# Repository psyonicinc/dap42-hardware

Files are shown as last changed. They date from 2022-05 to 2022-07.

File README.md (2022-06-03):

# dap42-hardware

This is a design of the dap42 in KiCad v6 using the STM32F103C8, there is no technical reason for this design and this STM is overkill. The re-design only part availability reasons. This design is based on dap42 v2 and [dc37's dap42 v3 design](https://github.com/dc37/dap42-hardware). 

Please see the parent repo at [devanlai/dap42-hardware](https://github.com/devanlai/dap42-hardware) for details on the DAP42 project. 

This design primarily uses the [KiCad default libraries](https://gitlab.com/kicad/libraries) which are expected to be in the global library table. A few footprints not in the KiCad Libraries are included in dap42.pretty which is configured as a project specific library. 

Firmware for this version to follow.

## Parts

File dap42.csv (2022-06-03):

Source: | F:\Psyonic\repos\dap42-hardware\dap42.kicad_sch
Date: | 6/3/2022 4:39:25 PM
Tool: | Eeschema (6.0.5)
Generator: | C:\Program Files\KiCad\6.0\bin\scripting\plugins/bom_csv_grouped_by_value_with_fp.py
Component Count: | 32
Ref | Qnty | Value | Cmp name | Footprint | Description | Vendor
C1, | 1 | 1uF 0603 | C | Capacitor_SMD:C_0603_1608Metric_Pad1.08x0.95mm_HandSolder | Unpolarized capacitor
C2, | 1 | 4.7uF 0603 | C | Capacitor_SMD:C_0603_1608Metric_Pad1.08x0.95mm_HandSolder | Unpolarized capacitor
C3, | 1 | 100nF 0402 | C | Capacitor_SMD:C_0402_1005Metric_Pad0.74x0.62mm_HandSolder | Unpolarized capacitor
C4, C5, C6, C7, C8, C9, C10, | 7 | 0.1uF 0402 | C | Capacitor_SMD:C_0402_1005Metric_Pad0.74x0.62mm_HandSolder | Unpolarized capacitor
D1, | 1 | 5.6V | D_Zener | Diode_SMD:D_SOD-123F | Zener diode
D2, | 1 | Green 0603 | LED | LED_SMD:LED_0603_1608Metric_Pad1.05x0.95mm_HandSolder | Light emitting diode
D3, | 1 | LED_GBAR | LED_GBAR | dap42:B38G3RGB | RGB LED, green/blue/anode/red
F1, | 1 | PTC 250mA 1206 | Polyfuse | Fuse:Fuse_1206_3216Metric_Pad1.42x1.75mm_HandSolder | Resettable fuse, polymeric positive temperature coefficient
J1, | 1 | USB_B_Micro | USB_B_Micro | Connector_USB:USB_Micro-B_Molex_47346-0001 | USB Micro Type B connector
J2, | 1 | Conn_02x05_Odd_Even | Conn_02x05_Odd_Even | dap42:IDC-Header_2x05_Pitch1.27mm_Straight | Generic connector, double row, 02x05, odd/even pin numbering scheme (row 1 odd numbers, row 2 even numbers), script generated (kicad-library-utils/schlib/autogen/connector/)
J4, | 1 | Conn_01x04 | Conn_01x04 | Connector_PinHeader_2.54mm:PinHeader_1x04_P2.54mm_Vertical | Generic connector, single row, 01x04, script generated (kicad-library-utils/schlib/autogen/connector/)
R2, R4, R5, R6, R7, R8, R10, | 7 | 1k 0402 | R_US | Resistor_SMD:R_0402_1005Metric_Pad0.72x0.64mm_HandSolder | Resistor, US symbol
R3, | 1 | 4.7k 0603 | R_US | Resistor_SMD:R_0603_1608Metric_Pad0.98x0.95mm_HandSolder | Resistor, US symbol
R9, R11, | 2 | 10k 0402 | R_US | Resistor_SMD:R_0402_1005Metric_Pad0.72x0.64mm_HandSolder | Resistor, US symbol
R12, | 1 | 0 Ohm 0402 | R_US | Resistor_SMD:R_0402_1005Metric_Pad0.72x0.64mm_HandSolder | Resistor, US symbol
SW1, | 1 | SW_SPST | SW_SPST | Button_Switch_SMD:SW_Push_1P1T_NO_CK_KMR2 | Single Pole Single Throw (SPST) switch
U1, | 1 | WE-TVS-82400102 | WE-TVS-82400102 | Package_TO_SOT_SMD:SOT-23-6 | Low Capacitance TVS Diode Array, 2 Channels, SOT-23-6
U2, | 1 | SPX3819M5-L-3-3 | SPX3819M5-L-3-3 | Package_TO_SOT_SMD:SOT-23-5 | 500mA Low drop-out regulator, Fixed Output 3.3V, SOT-23-5
U3, | 1 | STM32F102C8Tx | STM32F102C8Tx | Package_QFP:LQFP-48_7x7mm_P0.5mm | ARM Cortex-M3 MCU, 64KB flash, 10KB RAM, 48MHz, 2-3.6V, 37 GPIO, LQFP-48

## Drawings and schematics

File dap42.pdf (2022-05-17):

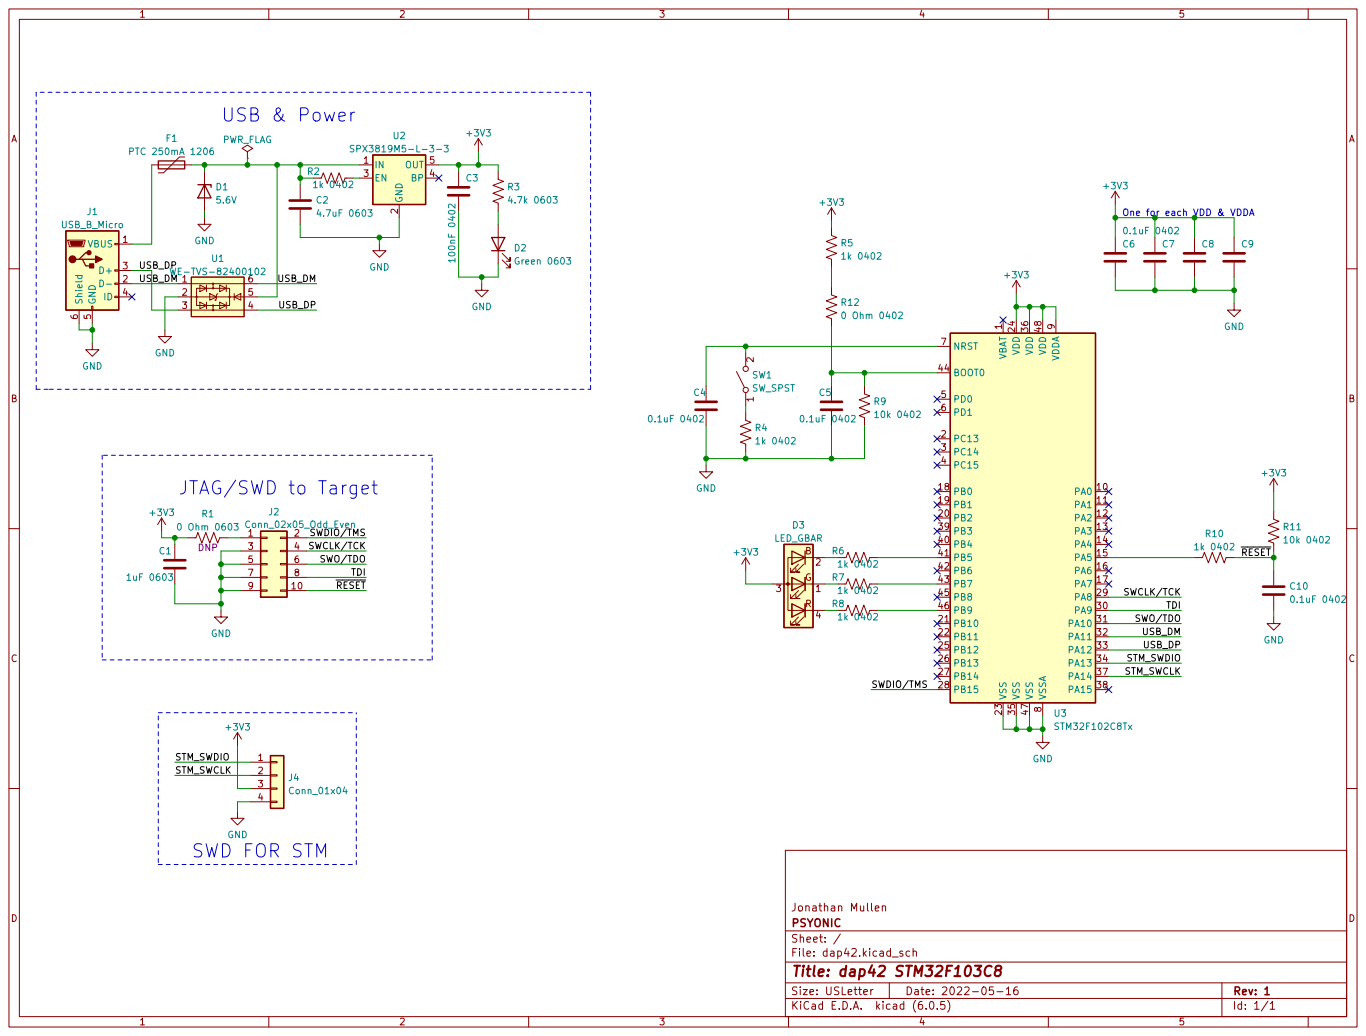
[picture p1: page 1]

One for each VDD & VDDA

1 PA0 10 PA1 11 PA2 12 PA3 13 PA4 14 PA5 15 PA6 16 PA7 17 PB0 18 PB1 19 PC13 2 PB2 20 PB10 21 PB11 22 VSS 23 VDD 24 PB12 25 PB13 26 PB14 27 PB15 28 PA8 29 PC14 3 PA9 30 PA10 31 PA11 32 PA12 33 PA13 34 VSS 35 VDD 36 PA14 37 PA15 38 PB3 39 PC15 4 PB4 40 PB5 41 PB6 42 PB7 43 BOOT0 44 PB8 45 PB9 46 VSS 47 VDD 48 PD0 5 PD1 6 NRST 7 VSSA

SWDIO/TMS JTAG/SWD to Target

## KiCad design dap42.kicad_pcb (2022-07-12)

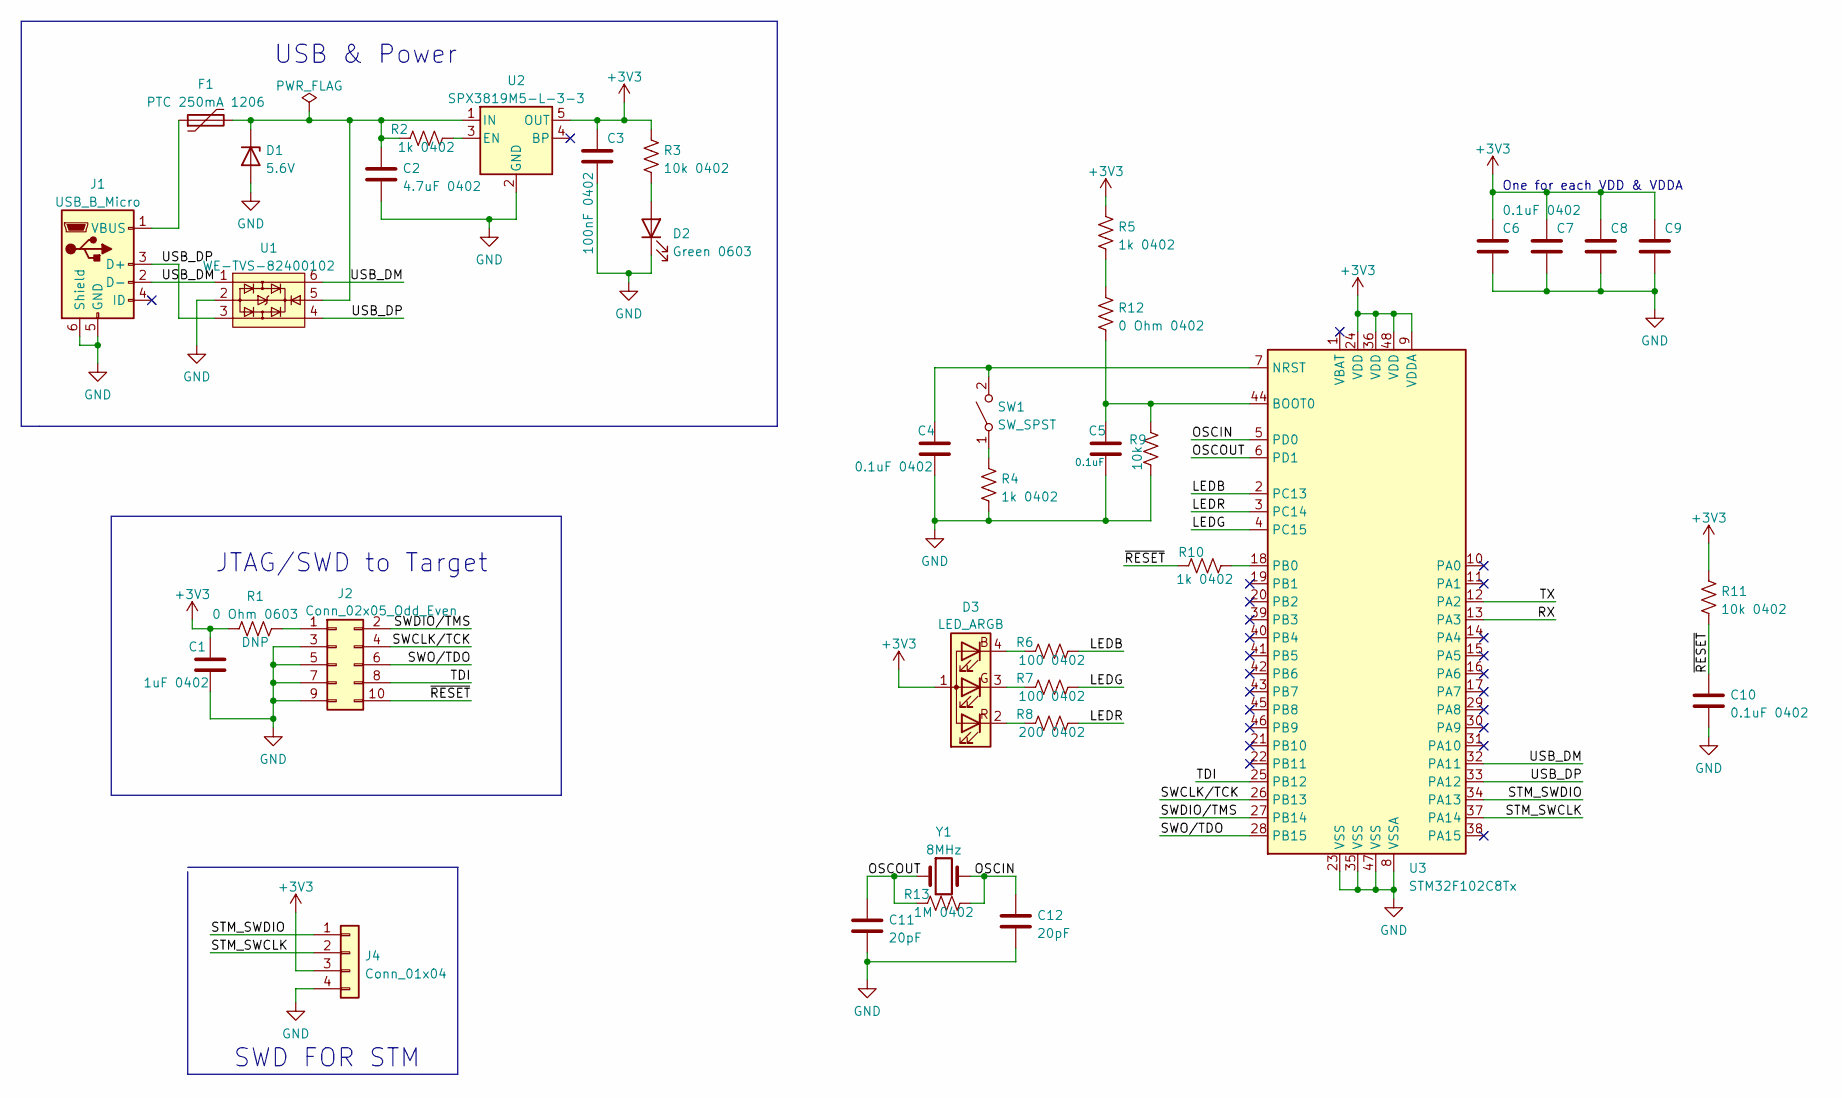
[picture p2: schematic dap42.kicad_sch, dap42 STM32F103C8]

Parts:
C1: 1uF 0402; C_0402_1005Metric_Pad0.74x0.62mm_HandSolder
C2: 4.7uF 0402; C_0402_1005Metric_Pad0.74x0.62mm_HandSolder
C3: 100nF 0402; C_0402_1005Metric_Pad0.74x0.62mm_HandSolder
C4, C6, C7, C8, C9, C10: 0.1uF 0402; C_0402_1005Metric_Pad0.74x0.62mm_HandSolder
C5: 0.1uF; C_0402_1005Metric_Pad0.74x0.62mm_HandSolder
C11, C12: 20pF; C_0402_1005Metric_Pad0.74x0.62mm_HandSolder
D1: 5.6V; D_SOD-123F; MPN NZH5V6B
D2: Green 0603; LED_0603_1608Metric_Pad1.05x0.95mm_HandSolder
D3: LED_ARGB; XZCMEDGCBD110W; MPN XZCMEDGCBD110W
F1: PTC 250mA 1206; Fuse_1206_3216Metric_Pad1.42x1.75mm_HandSolder
J1: USB_B_Micro; USB_Micro-B_Molex_47346-0001
J2: Conn_02x05_Odd_Even; IDC-Header_2x05_Pitch1.27mm_Straight
J4: Conn_01x04; PinHeader_1x04_P2.54mm_Vertical
R1: 0 Ohm 0603; R_0603_1608Metric_Pad0.98x0.95mm_HandSolder
R2, R4, R5, R10: 1k 0402; R_0402_1005Metric_Pad0.72x0.64mm_HandSolder
R3, R11: 10k 0402; R_0402_1005Metric_Pad0.72x0.64mm_HandSolder
R6, R7: 100 0402; R_0402_1005Metric_Pad0.72x0.64mm_HandSolder
R8: 200 0402; R_0402_1005Metric_Pad0.72x0.64mm_HandSolder
R9: 10k; R_0402_1005Metric_Pad0.72x0.64mm_HandSolder
R12: 0 Ohm 0402; R_0402_1005Metric_Pad0.72x0.64mm_HandSolder
R13: 1M 0402; R_0402_1005Metric_Pad0.72x0.64mm_HandSolder
SW1: SW_SPST; SW_Push_1P1T_NO_CK_KMR2
U1: WE-TVS-82400102; SOT-23-6
U2: SPX3819M5-L-3-3; SOT-23-5
U3: STM32F102C8Tx; LQFP-48_7x7mm_P0.5mm
Y1: 8MHz; Crystal_HC49-U_Vertical; MPN 8M20P2/49US

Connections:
+3V3: C1.1, C3.1, C6.1, C7.1, C8.1, C9.1, D3.1 (A), J4.3, R1.1, R3.1, R5.1, R11.1, U2.5 (OUT), U3.9 (VDDA), U3.24 (VDD), U3.36 (VDD), U3.48 (VDD)
/LEDB: R6.1, U3.2 (PC13)
/LEDG: R7.1, U3.4 (PC15)
/LEDR: R8.1, U3.3 (PC14)
/OSCIN: C12.1, R13.1, U3.5 (PD0), Y1.2
/OSCOUT: C11.1, R13.2, U3.6 (PD1), Y1.1
/RX: U3.13 (PA3)
/STM_SWCLK: J4.2, U3.37 (PA14)
/STM_SWDIO: J4.1, U3.34 (PA13)
/SWCLK/TCK: J2.4, U3.26 (PB13)
/SWDIO/TMS: J2.2, U3.27 (PB14)
/SWO/TDO: J2.6, U3.28 (PB15)
/TDI: J2.8, U3.25 (PB12)
/TX: U3.12 (PA2)
/USB_DM: J1.2 (D-), U1.1, U1.6, U3.32 (PA11)
/USB_DP: J1.3 (D+), U1.3, U1.4, U3.33 (PA12)
/~RESET: C10.1, J2.10, R10.1, R11.2
GND: C1.2, C2.2, C3.2, C4.2, C5.2, C6.2, C7.2, C8.2, C9.2, C10.2, C11.2, C12.2, D1.2 (A), D2.1 (K), J1.5 (GND), J1.6 (Shield), J2.3, J2.5, J2.7, J2.9, J4.4, R4.2, R9.2, U1.2, U2.2 (GND), U3.8 (VSSA), U3.23 (VSS), U3.35 (VSS), U3.47 (VSS)
unnamed: C2.1, D1.1 (K), F1.2, R2.1, U1.5, U2.1 (IN)
unnamed: C4.1, SW1.2 (B), U3.7 (NRST)
unnamed: C5.1, R9.1, R12.2, U3.44 (BOOT0)
unnamed: D2.2 (A), R3.2
unnamed: D3.2 (RK), R8.2
unnamed: D3.3 (GK), R7.2
unnamed: D3.4 (BK), R6.2
unnamed: F1.1, J1.1 (VBUS)
unnamed: J2.1, R1.2
unnamed: R2.2, U2.3 (EN)
unnamed: R4.1, SW1.1 (A)
unnamed: R10.2, U3.18 (PB0)
unnamed: R5.2, R12.1

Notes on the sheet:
SWD FOR STM
USB & Power
One for each VDD & VDDA
JTAG/SWD to Target

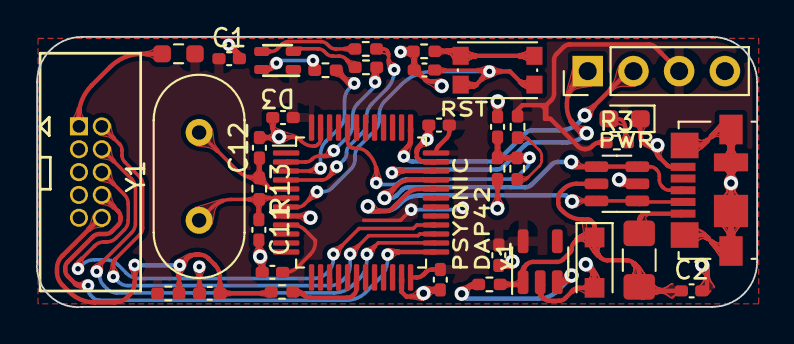
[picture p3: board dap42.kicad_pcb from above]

Board: 2 copper layers, 40.0 x 15.0 mm, 37 parts (0 on the bottom side), 29 nets.

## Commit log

2022-05-16 KiCad DAP42 STMF103C8
    [Board.gbr, BoardOutline.gbr, Bottom.gbr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]
2022-05-16 Fab files
    [dap42-B_Adhesive.gbr, dap42-B_Cu.gbr, dap42-B_Fab.gbr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]
2022-05-17 Add dimensions, add pdf of schematic
    [dap42.kicad_pcb]
2022-06-03 Add BOM and Pick/Place CSV
    [dap42.csv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]
2022-07-12 Add crystal
    [dap42.kicad_pcb, dap42.kicad_sch]
